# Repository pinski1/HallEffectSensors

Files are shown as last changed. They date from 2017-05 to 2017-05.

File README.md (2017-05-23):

# Hall Effect Sensors

Hall effect sensors for brushless outrunner motors.

This repo contains Hall Effect Sensor PCBs for both internal and external sensors for a few motor diameters.

Many hobby brushless motors do not come with hall effect sensors for position information. By adding one of these boards, aligning it correctly you can pick up the rotation and improve low speed torque of your motor.

These particular ones are designed for 12 slot, 14 pole brushless motors, however the files do contain the formulae to calculate the nessesary spacing for different pole counts.

These versions/copies were inspired by Charles Guan at http://www.etotheipiplusone.net/

## Purchasing

I'm planning to sell these on Tindie at some point.

If you're in the US you may be better served by purchasing from http://e0designs.com/products/hall-effect-sensor-board/

## Parts List

A1221 hall effect sensor
100nF capacitor
ferrite bead
wires
mounting hardware

## Alignment Instructions

1. loosely affix the sensor array in it's mounting point. It will need to be slid sideways to align it.
2. Line up the center sensor with a slot on the stator laminations.
3. Complete.

For a better guide check out: http://e0designs.com/documentation/hall-effect-sensor-board-adapter-installation/ and http://e0designs.com/documentation/finding-motor-phase-sensor-combinations/

# Licence
<br />This work is licensed under a <a rel="license" href="http://creativecommons.org/licenses/by/4.0/">Creative Commons Attribution 4.0 International License</a>.

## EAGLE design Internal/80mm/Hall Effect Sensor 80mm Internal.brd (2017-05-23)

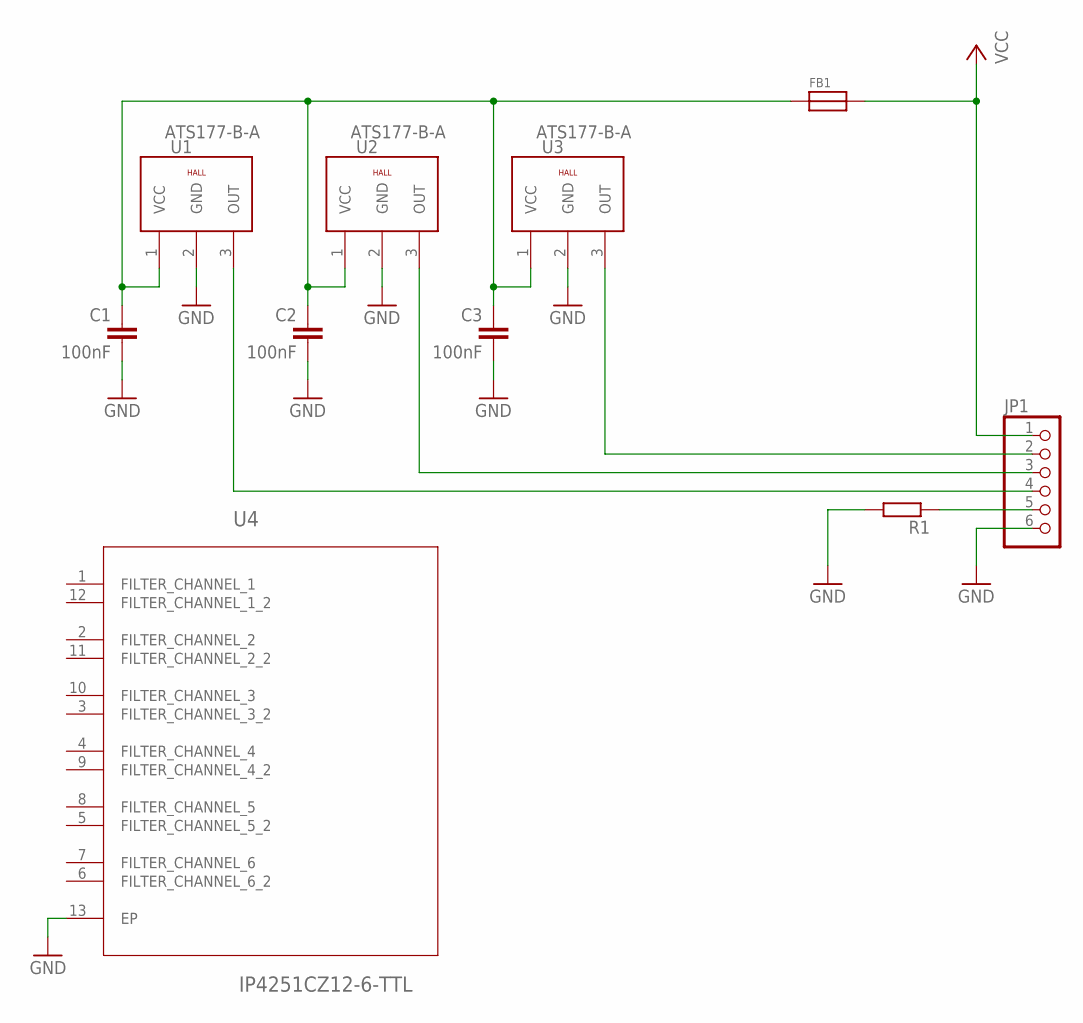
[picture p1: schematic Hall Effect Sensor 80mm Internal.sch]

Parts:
C1, C2, C3: 100nF; C0603; MPN CGA3E2X7R1H104K080AA
FB1: FERRITE; 0603; MPN BLM18TG601TN1D
JP1: PINHD-1X6; 1X06
R1: R-EU_R0603; R0603
U1, U2, U3: ATS177-B-A; 3PINS1,27; MPN A1221LUA-T
U4: IP4251CZ12-6-TTL; SON40P135X250X55-13N

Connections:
GND: C1.2, C2.2, C3.2, JP1.6, R1.2, U1.2 (GND), U2.2 (GND), U3.2 (GND), U4.13 (EP)
unnamed: JP1.5, R1.1
OUT1: JP1.4, U1.3 (OUT)
OUT2: JP1.3, U2.3 (OUT)
OUT3: JP1.2, U3.3 (OUT)
VCC: FB1.2, JP1.1
VDD: C1.1, C2.1, C3.1, FB1.1, U1.1 (VCC), U2.1 (VCC), U3.1 (VCC)

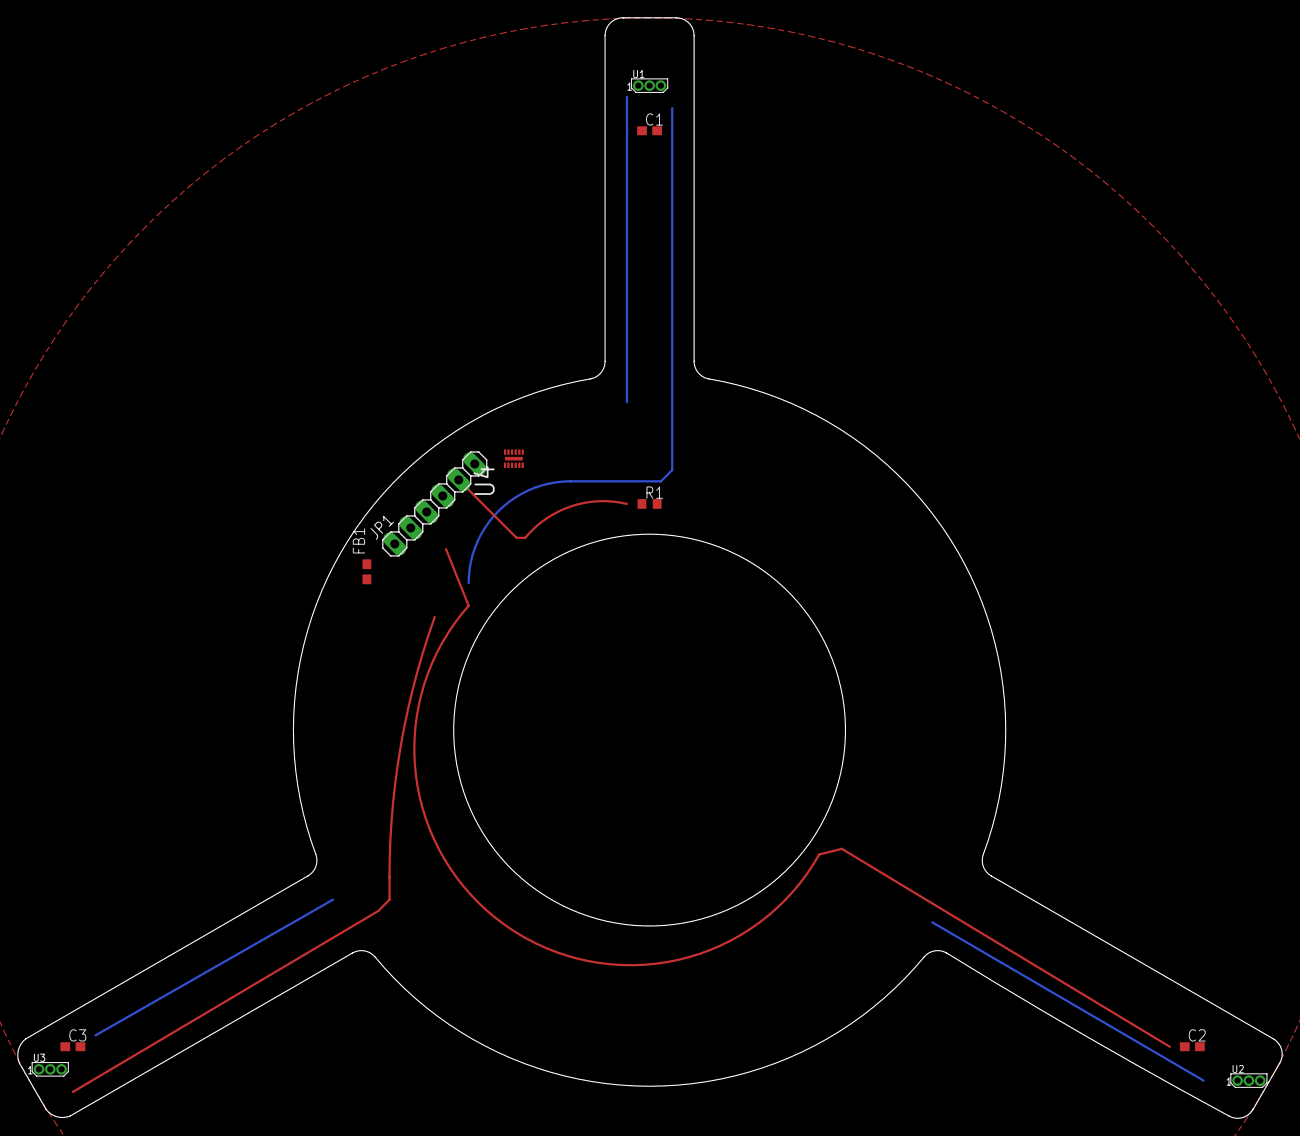
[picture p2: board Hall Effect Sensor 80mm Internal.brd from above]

Board: 2 copper layers, 142.0 x 123.6 mm, 10 parts (0 on the bottom side), 7 nets.

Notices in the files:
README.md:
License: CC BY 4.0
